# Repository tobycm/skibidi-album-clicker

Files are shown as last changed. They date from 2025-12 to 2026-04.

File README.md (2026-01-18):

# skibidi-album-clicker

alllllll iiiiii wanttttt forr christmassssssssssss, is a tiny 3d printed with some pcb to display photos of the year 🤑🤑🤑🤑🤑🤑🤑🤑🤑

this is a perfect gift for your loved ones. featuring a seeed xiao rp2040 with 2mb of flash, a 1.3 inch oled display, you can make them take a trip down memory lane with photos, or torture them idk.

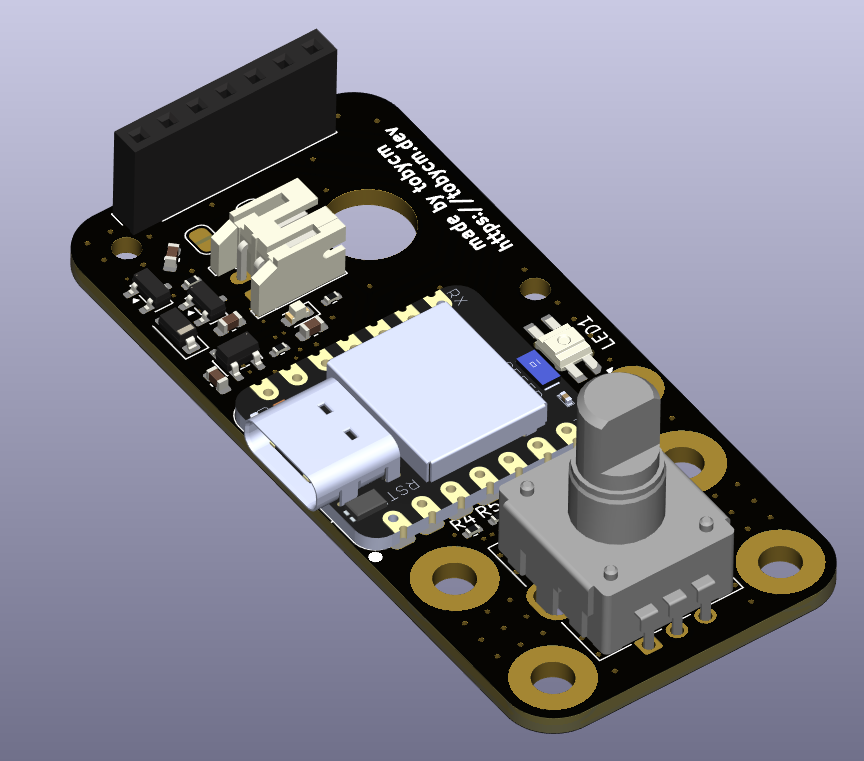
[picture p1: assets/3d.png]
3d render


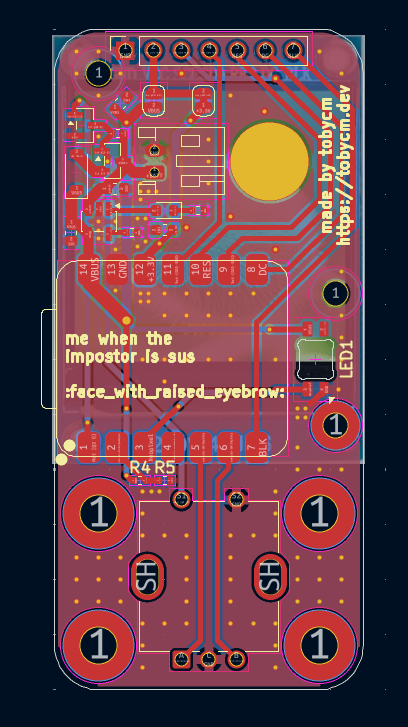
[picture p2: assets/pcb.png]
pcb


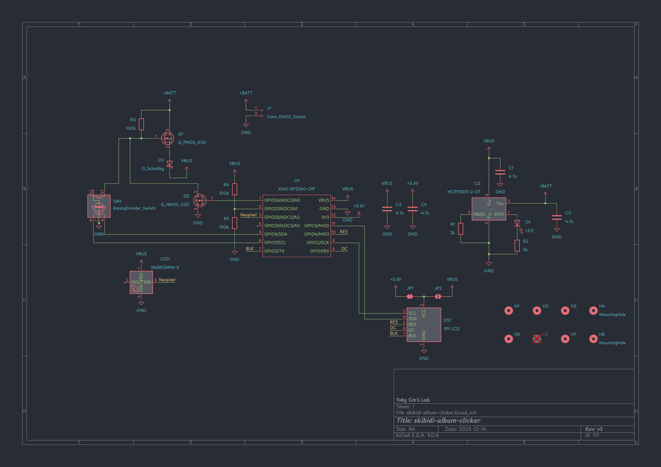
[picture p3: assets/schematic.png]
schematic


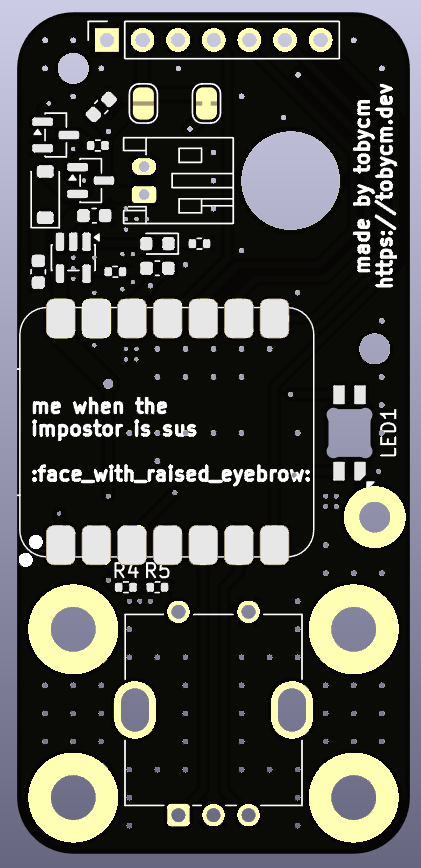
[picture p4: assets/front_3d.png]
front 3d


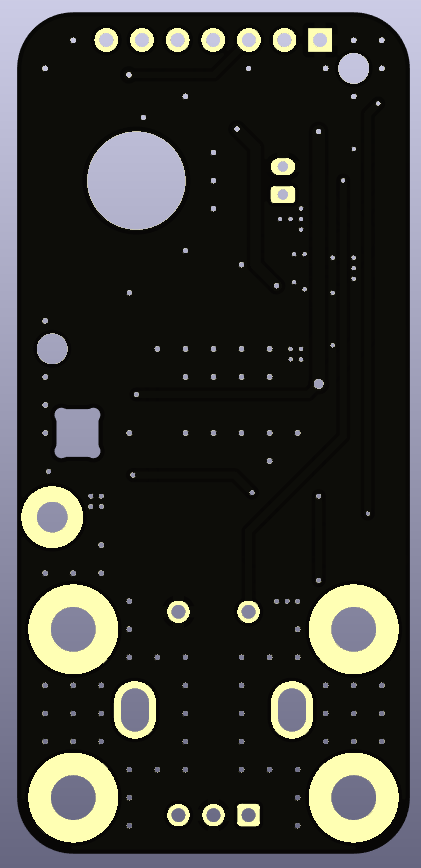
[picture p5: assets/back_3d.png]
back 3d


## Bill of Materials

| Description | Quantity | Part # | Unit Price | Extended Price USD |
| --- | --- | --- | --- | --- |
| 20V 5A 52M@4.5V,2.4A 1.31W 1V 1 | 10 | FDN304P | 0.099 | 0.99 |
| IC BATT CNTL LI-ION 1CEL SOT23-5 | 5 | MCP73832T-2ACI/OT | 0.76 | 3.80 |
| 20V 3.77A 750MW 33MR@4.5V,5A 850 | 10 | SI2312A | 0.109 | 1.09 |
| RES 2K OHM 1% 1/16W 0402 | 25 | RMCF0402FT2K00 | 0.0048 | 0.12 |
| RES 100K OHM 1% 1/16W 0402 | 50 | RC0402FR-07100KL | 0.0032 | 0.16 |
| RES 470 OHM 1% 1/16W 0402 | 50 | RC0402FR-07470RL | 0.003 | 0.15 |
| ENCODER INCRE QUAD HORIZN PC PIN | 5 | PEC12R-4217F-S0024 | 1.478 | 7.39 |
| ENCODER INCRE QUAD HORIZN PC PIN | 5 | PEC12R-4220F-S0024 | 1.478 | 7.39 |
| XIAO RP2040 | 1 | 102010428 | 4.68 | 4.68 |
| LED AMBER CLEAR 0603 SMD | 10 | 150060AS75000 | 0.15 | 1.50 |
| 60V 115MA 7.5@10V,500MA 225MW N | 10 | 2N7002 | 0.054 | 0.54 |
| DIODE SCHOTTKY 20V 1A SOD123 | 10 | MBRX120LF-TP | 0.236 | 2.36 |
| CAP CER 4.7UF 10V X5R 0603 | 50 | CL10A475KP8NNNC | 0.006 | 0.30 |
| Digikey | 1 | Shipping | 20 | 20.00 |
| Neopixel | 5 | SK6812MINI-E |  |  |
| PCB | 1 | JLCPCB PCB | 4.7 | 4.70 |
| Aliexpress |  | LCDs | 17 | 17.00 |
| **Total** |  |  |  | **72.17** |

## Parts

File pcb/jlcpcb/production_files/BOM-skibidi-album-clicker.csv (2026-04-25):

Comment | Designator | Footprint | LCSC | Quantity
100n |  | C_0603_1608Metric | C14663 | 0
10u | C1,C3,C5,C6,C7,C8 | C_0603_1608Metric | C96446 | 6
1k | R7 | R_0603_1608Metric | C2907002 | 1
2.49k | R1,R2,R3,R4,R5,R6,R8 | R_0603_1608Metric | C2930072 | 7
5.1k | R10,R9 | R_0603_1608Metric | C2907044 | 2
K2-1102AQ-H4CW-01 | SW2 | SW-TH_K2-1102BQ-G4CW-01 | C961738 | 1
LED | D1 | LED_0603_1608Metric | C965807 | 1
PY25Q128HA-SUH-IR | U1 | SOIC-8_5.3x5.3mm_P1.27mm | C5354566 | 1
RP2040-ZERO | U2 | COMM-SMD_RP2040-ZERO | C5350143 | 1
RotaryEncoder_Switch | SW1 | RotaryEncoder_Bourns_Vertical_PEC12R-3x17F-Sxxxx | C143801 | 1
USB_C_Receptacle_PowerOnly_6P | J2 | TYPE-C-SMD_TYPE-C-6P-073 | C25168796 | 1
Conn_01x02_Socket | J1 | JST_PH_S2B-PH-K_1x02_P2.00mm_Horizontal |  | 1
SPI LCD | DS1 | PinSocket_1x07_P2.54mm_Horizontal |  | 1
TP4057 | U3 | TSOT-23-6 |  | 1
ME6211C33M5 | U4 | SOT-23-5 |  | 1

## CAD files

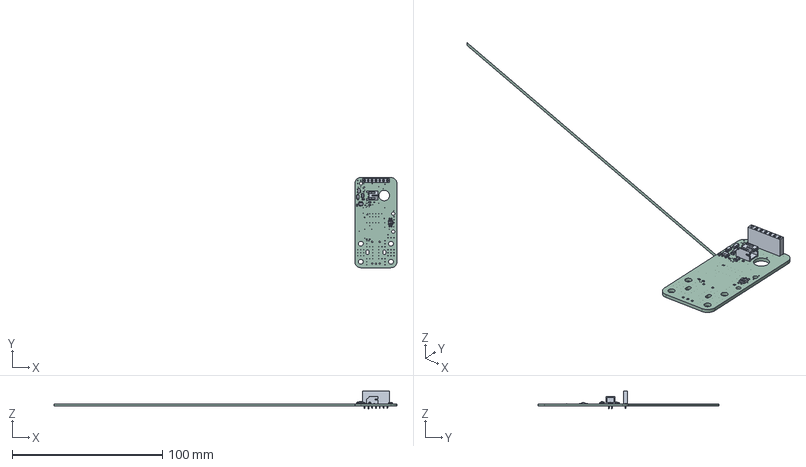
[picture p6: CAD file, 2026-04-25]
cad/skibidi-album-clicker.step
228.0 x 120.0 x 11.9 mm
R_0402_1005Metric x 5
C_0603_1608Metric x 4
LED_SK6812MINI-E
SOT-23 x 2
JST_PH_S2B-PH-K_1x02_P2.00mm_Horizontal
D_SOD-123
LED_0603_1608Metric
SOT-23-5
PinSocket_1x07_P2.54mm_Vertical
skibidi-album-clicker_PCB

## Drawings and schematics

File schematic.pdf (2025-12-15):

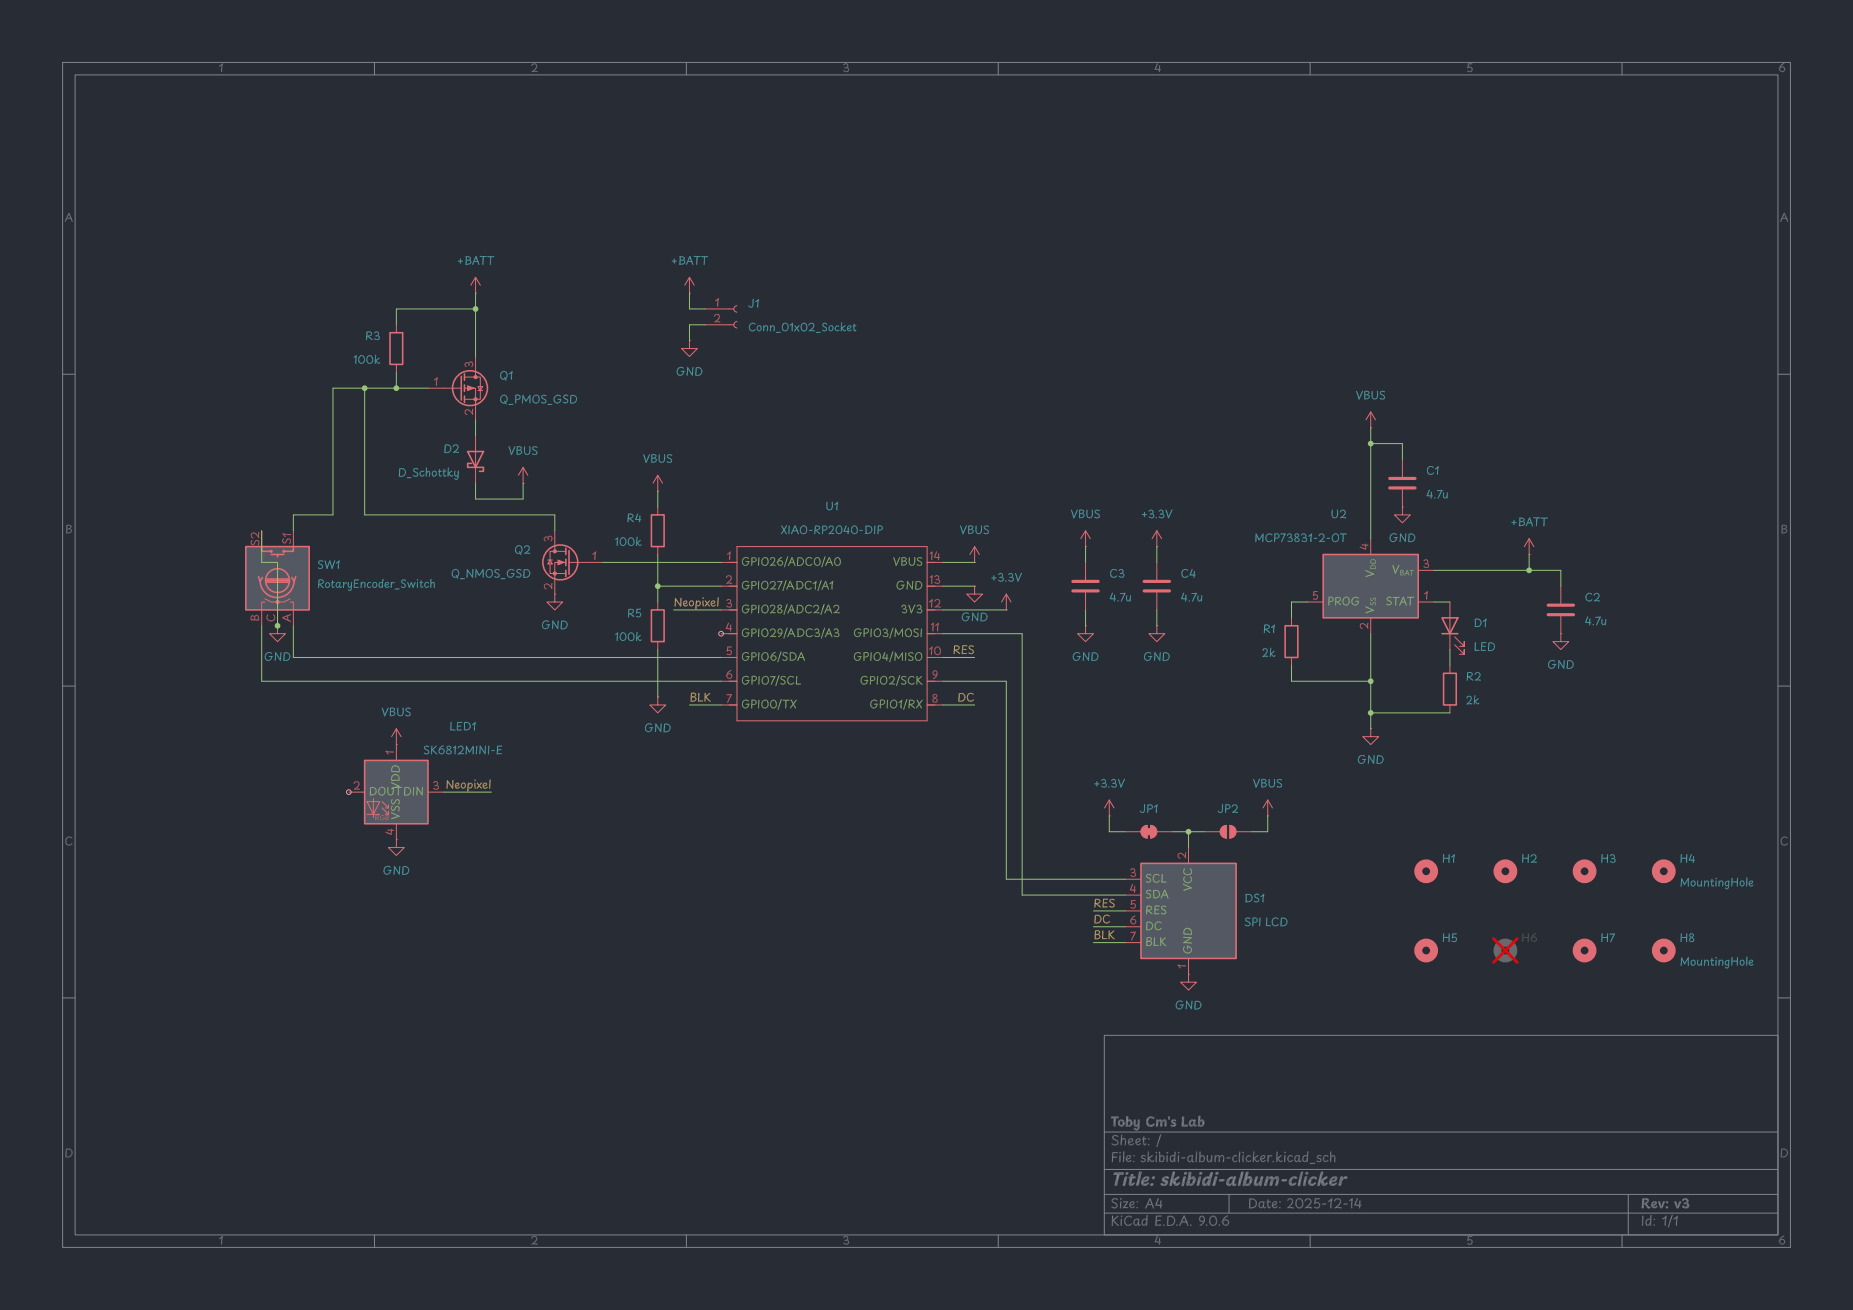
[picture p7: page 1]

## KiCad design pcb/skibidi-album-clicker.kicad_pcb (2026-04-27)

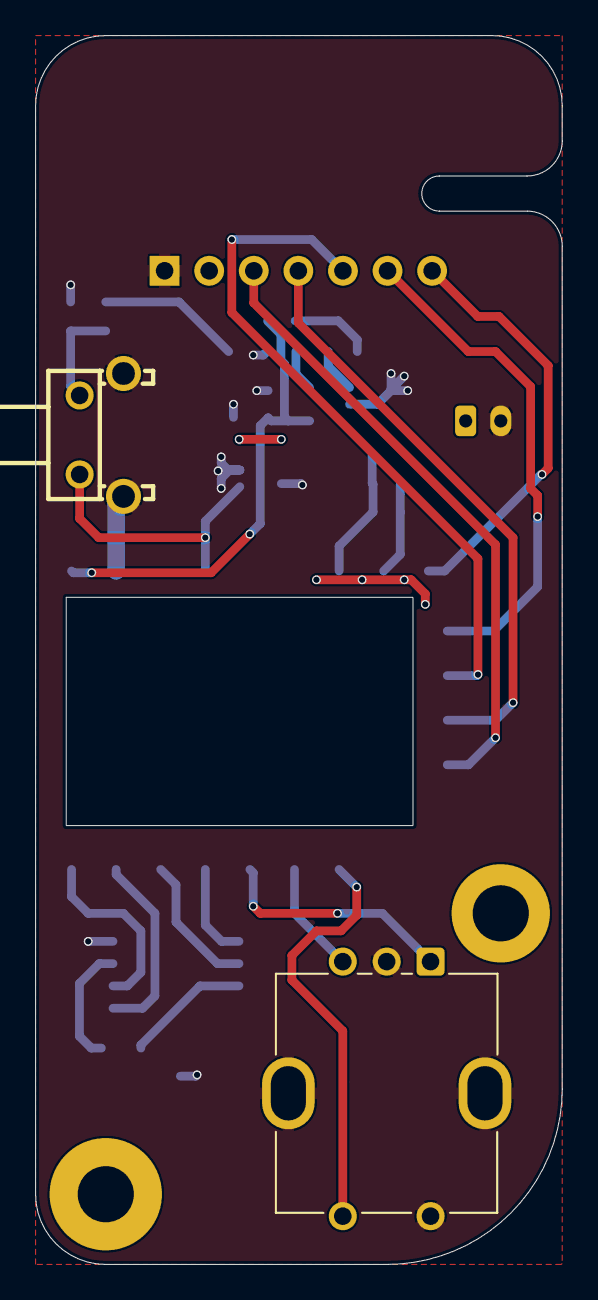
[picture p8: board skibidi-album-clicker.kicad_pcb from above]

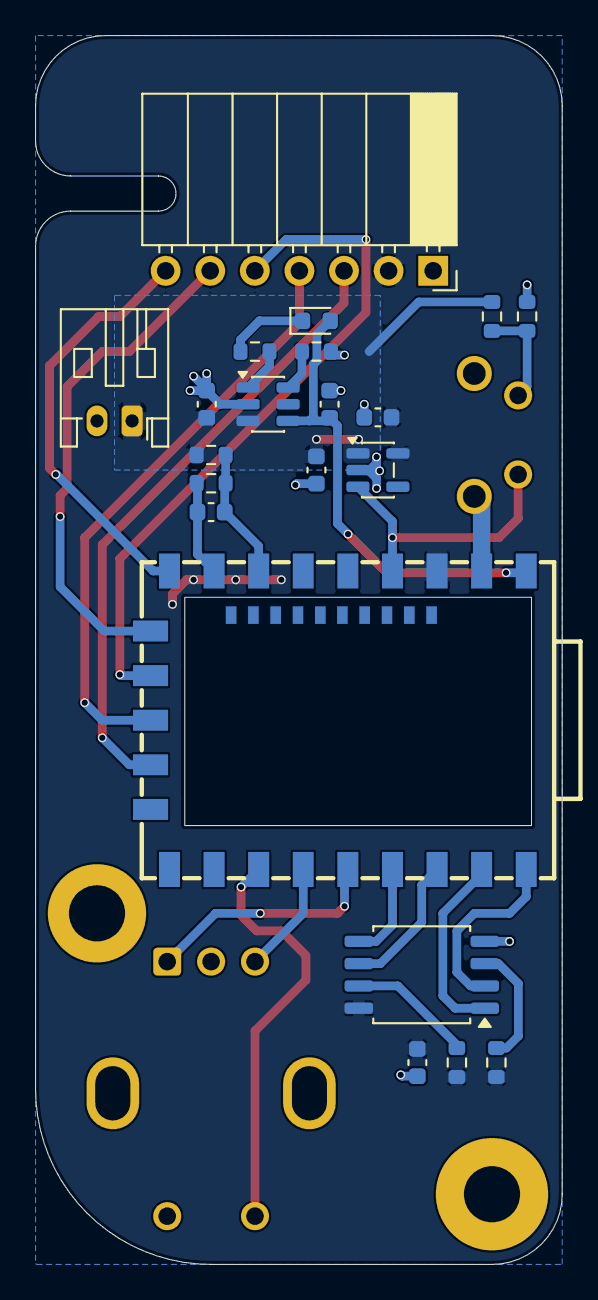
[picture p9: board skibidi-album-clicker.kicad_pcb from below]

Board: 2 copper layers, 30.0 x 70.0 mm, 25 parts (21 on the bottom side), 25 nets.

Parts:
C1, C5, C6, C7, C8: 10u; C_0603_1608Metric
C4: 100n; C_0603_1608Metric
D1: LED; LED_0603_1608Metric
DS1: SPI LCD; PinSocket_1x07_P2.54mm_Horizontal
H1, H2: MountingHole; MountingHole_3.2mm_M3_Pad
J1: Conn_01x02_Socket; JST_PH_S2B-PH-K_1x02_P2.00mm_Horizontal
R1, R2, R3, R4, R5, R6, R8: 2.49k; R_0603_1608Metric
R7: 1k; R_0603_1608Metric
SW1: RotaryEncoder_Switch_MP; RotaryEncoder_Bourns_Vertical_PEC12R-3x17F-Sxxxx
SW2: K2-1102AQ-H4CW-01; SW-TH_K2-1102BQ-G4CW-01
U1: PY25Q128HA-SUH-IR; SOIC-8_5.3x5.3mm_P1.27mm
U2: RP2040-ZERO; COMM-SMD_RP2040-ZERO
U3: TP4057; TSOT-23-6
U4: ME6211C33M5; SOT-23-5

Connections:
+3V3: C1.1, C8.1, DS1.2 (VCC), R1.1, R2.1, U1.8 (VCC), U2.21 (3V3), U4.5 (V_{OUT})
+5V: C5.1, D1.2 (A), U2.23 (5V), U3.4 (V_{CC})
+BATT: C6.1, C7.1, J1.1, R3.1, R5.1, U3.3 (BAT), U4.1 (V_{IN})
/A: SW1.A, U2.5 (GP4)
/B: SW1.B, U2.6 (GP5)
/BLK: DS1.7 (BLK), U2.15 (GP14)
/B_VOLT: C4.1, R5.2, R6.1, U2.17 (GP26)
/B_VOLT_REF: C4.2, R6.2, U2.16 (GP15)
/CS: U1.1 (~CS), U2.2 (GP1)
/DC: DS1.6 (DC), U2.14 (GP13)
/E_SW: SW1.S2, U2.7 (GP6)
/LDO_CE: SW2.2, U2.20 (GP29), U4.3 (CE)
/MISO: U1.2 (DO/IO_{1}), U2.1 (GP0)
/MOSI: U1.5 (DI/IO_{0}), U2.4 (GP3)
/MOSI2: DS1.4 (SDA), U2.12 (GP11)
/RES: DS1.5 (RES), U2.13 (GP12)
/SCK: U1.6 (CLK), U2.3 (GP2)
/SCK2: DS1.3 (SCL), U2.11 (GP10)
GND: C1.2, C5.2, C6.2, C7.2, C8.2, DS1.1 (GND), J1.2, R4.2, R8.2, SW1.C, SW1.S1, SW1.SH, SW2.3, SW2.4, U1.4 (GND), U2.22 (GND), U3.2 (GND), U4.2 (V_{SS})
unnamed: D1.1 (K), R7.1
unnamed: R3.2, R4.1, SW2.1
unnamed: R2.2, U1.7 (~HOLD/~RESET/IO_{3})
unnamed: R1.2, U1.3 (~WP/IO_{2})
unnamed: R8.1, U3.6 (PROG)
unnamed: R7.2, U3.1 (~CHRG)

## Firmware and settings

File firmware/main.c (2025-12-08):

#include <stdio.h>
#include "pico/stdlib.h"
#include "hardware/spi.h"
#include "hardware/dma.h"
#include "JPEGDEC.h"
#include "image_data.h"

#define TFT_SPI_PORT spi0
#define TFT_PIN_SCK 2
#define TFT_PIN_MOSI 3
#define TFT_PIN_CS 1
#define TFT_PIN_DC 0
#define TFT_PIN_RST 26
#define TFT_PIN_BL 27

#define TFT_WIDTH 240
#define TFT_HEIGHT 240

JPEGDEC jpeg;

void tft_write_command(uint8_t cmd)
{
    gpio_put(TFT_PIN_DC, 0);
    gpio_put(TFT_PIN_CS, 0);
    spi_write_blocking(TFT_SPI_PORT, &cmd, 1);
    gpio_put(TFT_PIN_CS, 1);
}

void tft_write_data(uint8_t *data, size_t len)
{
    gpio_put(TFT_PIN_DC, 1);
    gpio_put(TFT_PIN_CS, 0);
    spi_write_blocking(TFT_SPI_PORT, data, len);
    gpio_put(TFT_PIN_CS, 1);
}

void tft_set_window(uint16_t x, uint16_t y, uint16_t w, uint16_t h)
{
    uint8_t caset[] = {0, (uint8_t)x, 0, (uint8_t)(x + w - 1)};
    uint8_t raset[] = {0, (uint8_t)y, 0, (uint8_t)(y + h - 1)};

    tft_write_command(0x2A);
    tft_write_data(caset, 4);
    tft_write_command(0x2B);
    tft_write_data(raset, 4);
    tft_write_command(0x2C);
}

void tft_init()
{
    spi_init(TFT_SPI_PORT, 62500000);
    gpio_set_function(TFT_PIN_SCK, GPIO_FUNC_SPI);
    gpio_set_function(TFT_PIN_MOSI, GPIO_FUNC_SPI);

    gpio_init(TFT_PIN_CS);
    gpio_set_dir(TFT_PIN_CS, GPIO_OUT);
    gpio_put(TFT_PIN_CS, 1);
    gpio_init(TFT_PIN_DC);
    gpio_set_dir(TFT_PIN_DC, GPIO_OUT);
    gpio_put(TFT_PIN_DC, 1);

    if (TFT_PIN_RST != -1)
    {
        gpio_init(TFT_PIN_RST);
        gpio_set_dir(TFT_PIN_RST, GPIO_OUT);
        gpio_put(TFT_PIN_RST, 1);
        sleep_ms(100);
        gpio_put(TFT_PIN_RST, 0);
        sleep_ms(100);
        gpio_put(TFT_PIN_RST, 1);
        sleep_ms(200);
    }

    if (TFT_PIN_BL != -1)
    {
        gpio_init(TFT_PIN_BL);
        gpio_set_dir(TFT_PIN_BL, GPIO_OUT);
        gpio_put(TFT_PIN_BL, 1);
    }

    tft_write_command(0x11);
    sleep_ms(120);
    tft_write_command(0x3A);
    uint8_t color[] = {0x55};
    tft_write_data(color, 1);
    tft_write_command(0x36);
    uint8_t rot[] = {0x00};
    tft_write_data(rot, 1);
    tft_write_command(0x21);
    tft_write_command(0x29);
}

int drawMCU(JPEGDRAW *pDraw)
{

    tft_set_window(pDraw->x, pDraw->y, pDraw->iWidth, pDraw->iHeight);

    gpio_put(TFT_PIN_DC, 1);
    gpio_put(TFT_PIN_CS, 0);

    spi_write_blocking(TFT_SPI_PORT, (uint8_t *)pDraw->pPixels, pDraw->iWidth * pDraw->iHeight * 2);

    gpio_put(TFT_PIN_CS, 1);
    return 1;
}

int main()
{
    stdio_init_all();

    gpio_init(0);
    gpio_set_dir(0, GPIO_OUT);
    gpio_put(0, 1);

    tft_init();

    tft_set_window(0, 0, TFT_WIDTH, TFT_HEIGHT);

    while (true)
    {

        for (int i = 0; i < total_images; i++)
        {

            if (jpeg.openFLASH((uint8_t *)image_list[i], image_sizes[i], drawMCU))
            {

                jpeg.setPixelType(RGB565_BIG_ENDIAN);
                jpeg.decode(0, 0, 0);
                jpeg.close();
            }

            sleep_ms(3000);
        }
    }
}

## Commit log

2025-12-07 move bom and add more render
    [bom.csv]
2025-12-15 add schematic
    [skibidi-album-clicker.kicad_sch]
2026-01-18 add gerber and update bom
    [BOM-skibidi-album-clicker.csv, bom.csv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]
2026-04-27 finished routing yeahhhh
    [skibidi-album-clicker.kicad_pcb, skibidi-album-clicker.kicad_sch]
